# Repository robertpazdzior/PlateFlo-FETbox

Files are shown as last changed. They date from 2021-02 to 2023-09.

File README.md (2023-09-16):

# PlateFlo FETbox - Hardware Controller
FETbox hardware controller for the PlateFlo plate-scale perfusion tissue culture
system.

See [publication](https://doi.org/10.1016/j.ohx.2021.e00222) and [ReadTheDocs](https://plateflo.readthedocs.io) for a detailed description of the whole
system and documentation of its components. 

## Description
Hosted here are all of the necessary files to build a FETbox hardware
controller. Source files are also included should you need to make 
modifications for your application.
* [Enclosure](./Enclosure/STLs)
    * [STLs]() - for 3D printing
    * [CAD](./Enclosure/CAD) - STEP and F3D complete device models
* [PCB](./PCB)
    * [JLCPCB](https://jlcpcb.com/) CAM files (for PCB ordering)
    * [EAGLE](https://www.autodesk.com/products/eagle/overview) `.SCH` and `.BRD` [source files](./PCB/EAGLE)
* Arduino Nano FETbox [firmware](./Firmware_FETbox)

## License
This project is copyright of Robert Pazdzior (2020-2021)

It is provided under the terms of the [CERN Open Hardware License
(CERN-OHL-W)](https://cern-ohl.web.cern.ch/home). A copy of the license is
included [here](LICENSE).

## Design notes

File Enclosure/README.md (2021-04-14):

# Enclosure 3D Files
FETbox 3D-printing and CAD design resources. See [Build Guide](https://plateflo.readthedocs.io/en/latest/hardware/build_guide.html#d-printing-guidelines) for 3D-printing guidelines & assembly.

File | Description
---:  | :---
STLs\\*.stl | 3D print files. Oriented for FDM 3D-printing.
CAD\FETbox_complete.f3d | Complete Fusion360 model, including key board components.
CAD\FETbox_complete.step | As above, but compatible with open-source software.

## CAD Model Exploded Render
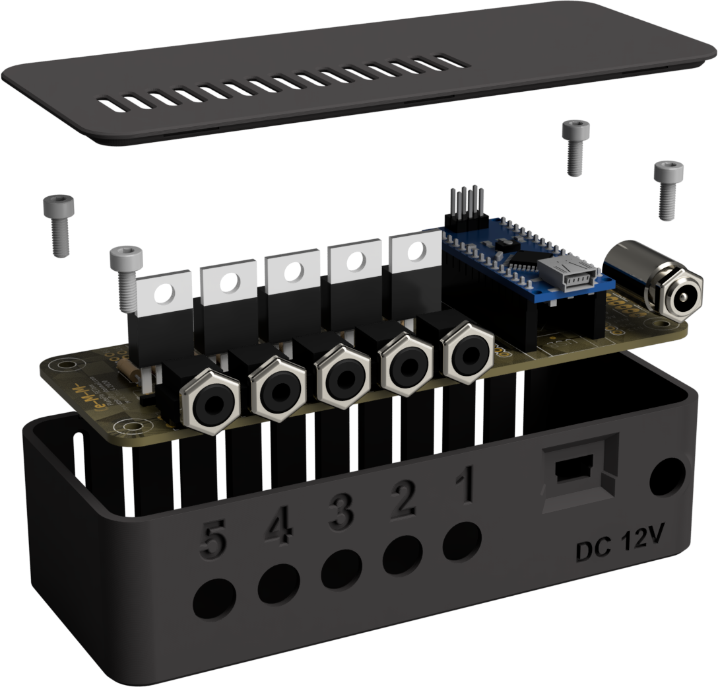
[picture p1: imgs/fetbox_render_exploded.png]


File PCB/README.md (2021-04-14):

# PCB
See [project documentation](https://plateflo.readthedocs.io/en/latest/hardware/build_guide.html#fetbox-hardware-controller) for manufacture and assembly guides.

## Files
File | Description
--- | ---
FETbox_rev0_Gerber_JLCPCB.zip | JLCPCB CAM (Gerber) files for production
EAGLE\FETbox_rev0_PCB.brd | EAGLE board
EAGLE\FETbox_rev0_PCB.sch | EAGLE schematic
EAGLE\\*.b#[0-9] | EAGLE routing support files
EAGLE\\*.pro | EAGLE auto-routing stats file
FETbox_rev0_schematic.pdf/dxf | Circuit diagram

## Overview
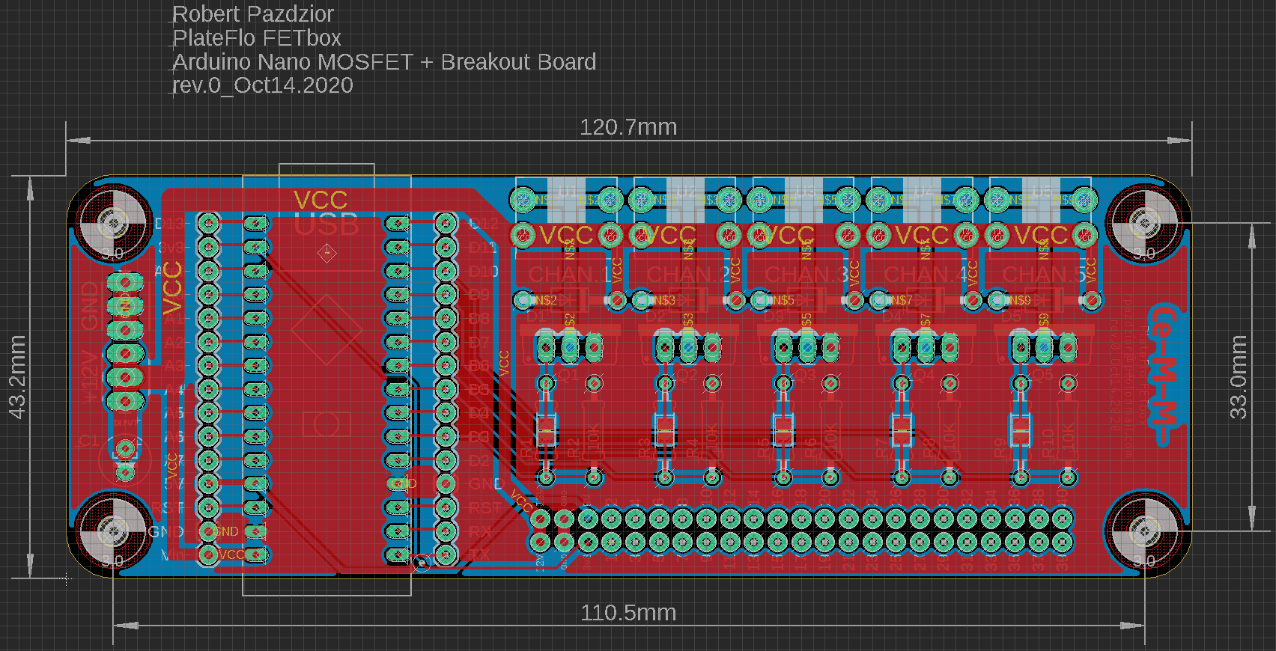
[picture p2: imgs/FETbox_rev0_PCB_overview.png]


## Top
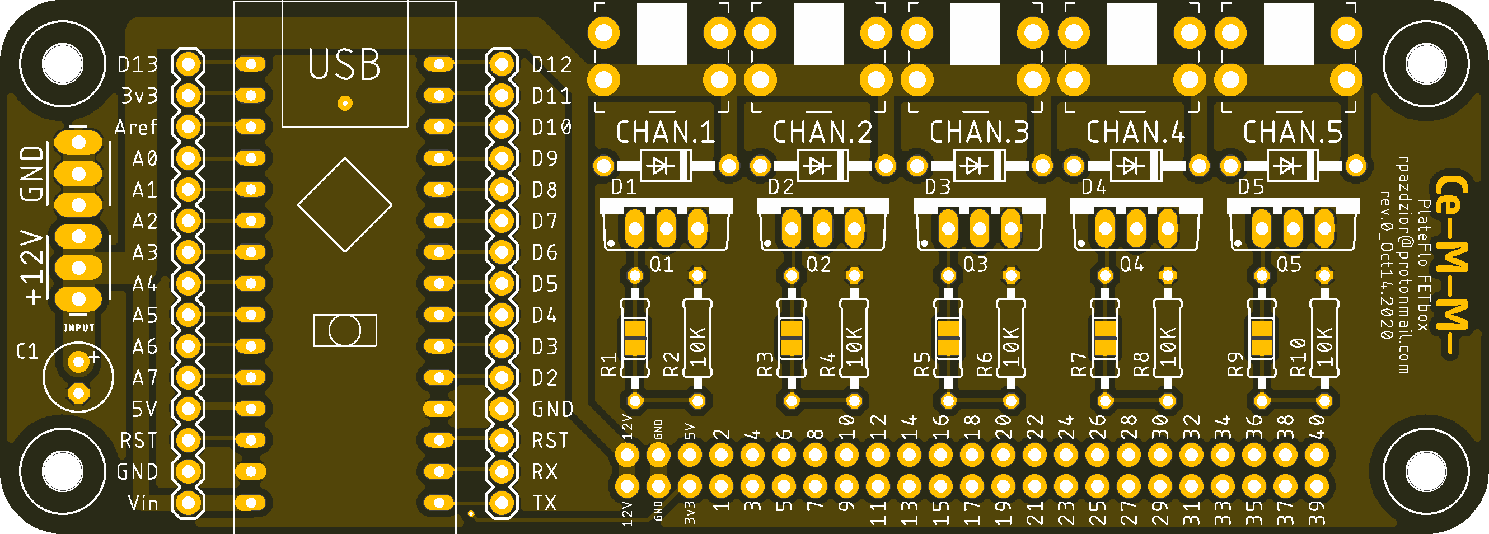
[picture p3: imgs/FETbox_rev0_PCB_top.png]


## Bottom
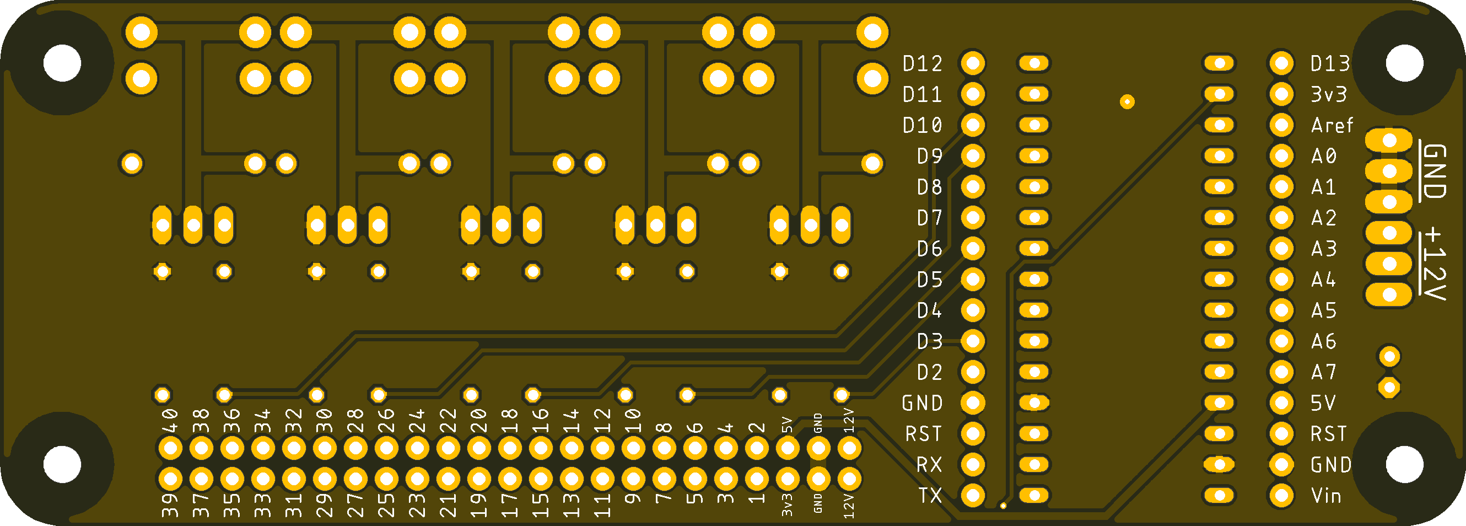
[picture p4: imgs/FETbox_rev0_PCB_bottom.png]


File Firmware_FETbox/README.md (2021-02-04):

# Firmware
FETbox firmware for the Arduino Nano v3. See documentation [here]().

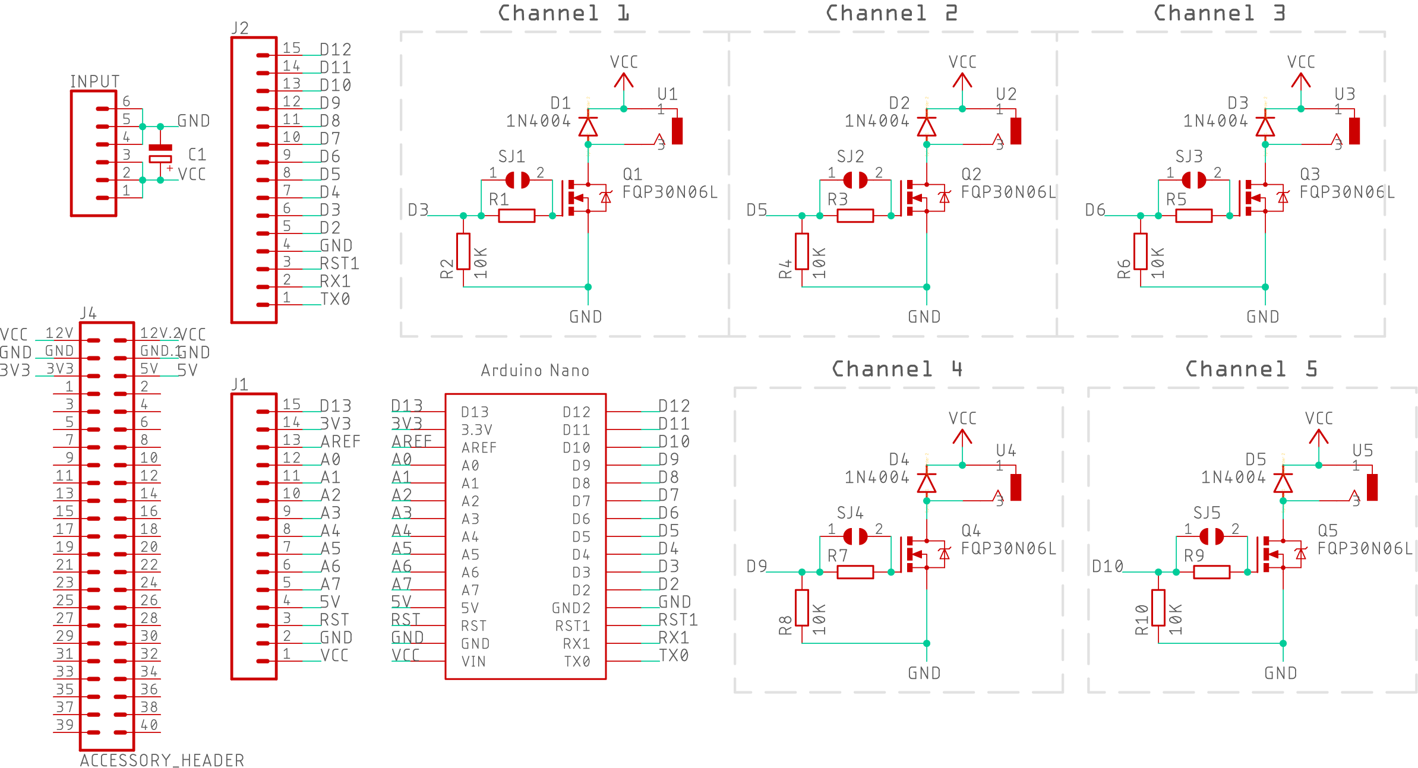
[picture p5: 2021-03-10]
imgs/FETbox_rev0_schematic.png

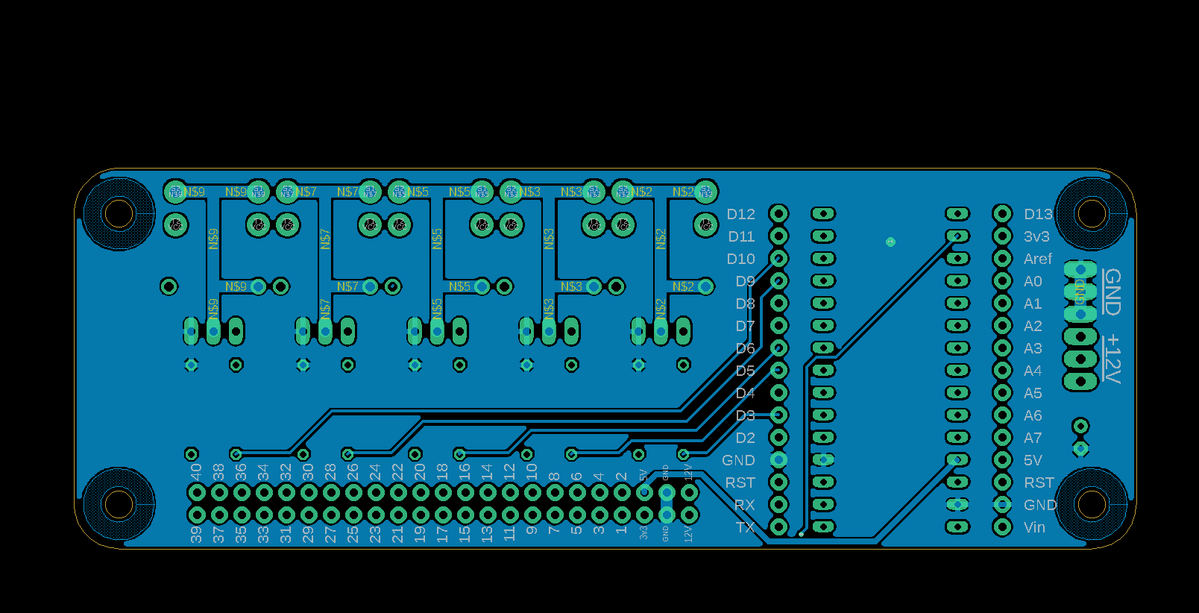
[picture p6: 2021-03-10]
imgs/PCB_bottom_copper.png

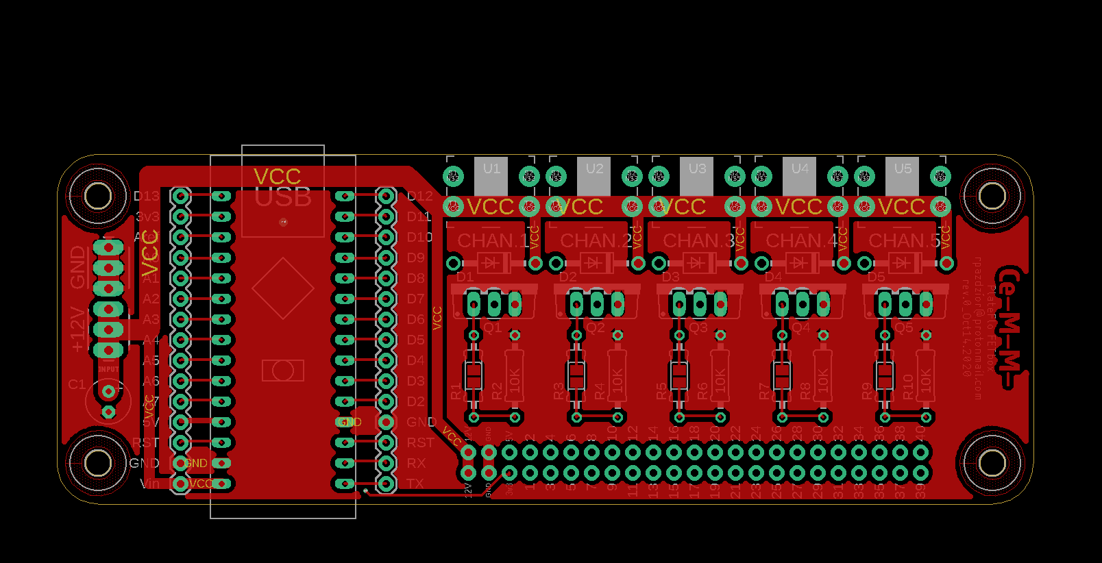
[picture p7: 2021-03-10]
imgs/PCB_top_copper.png

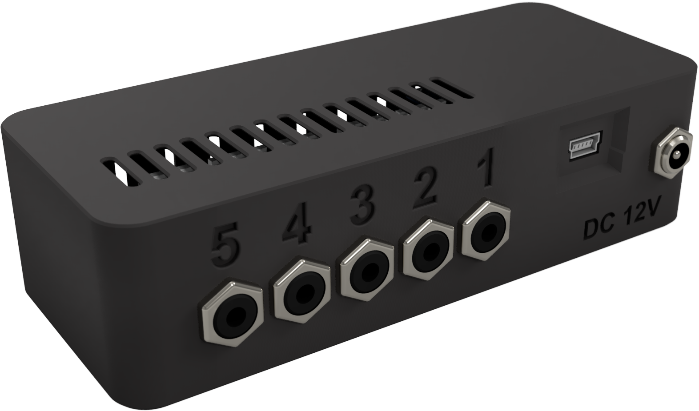
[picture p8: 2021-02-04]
imgs/fetbox_render.png

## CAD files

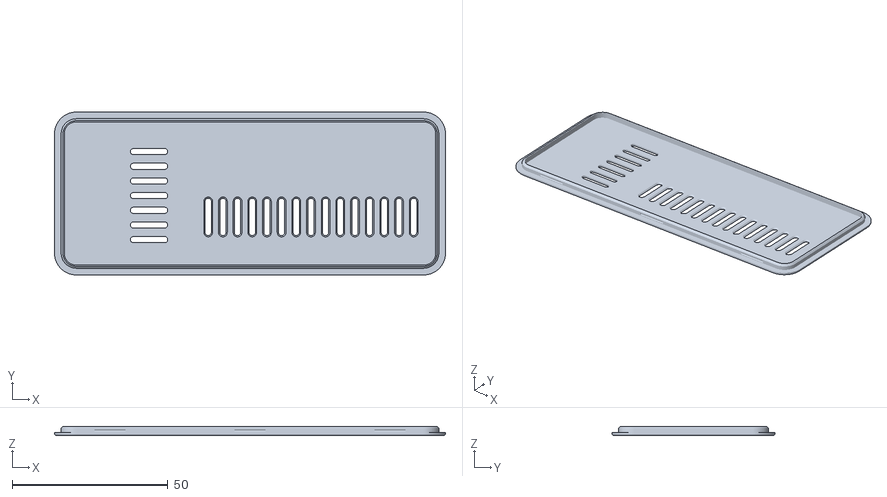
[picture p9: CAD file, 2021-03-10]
Enclosure/STLs/FETbox_enclosure_lid.stl
125.6 x 52.3 x 3.00

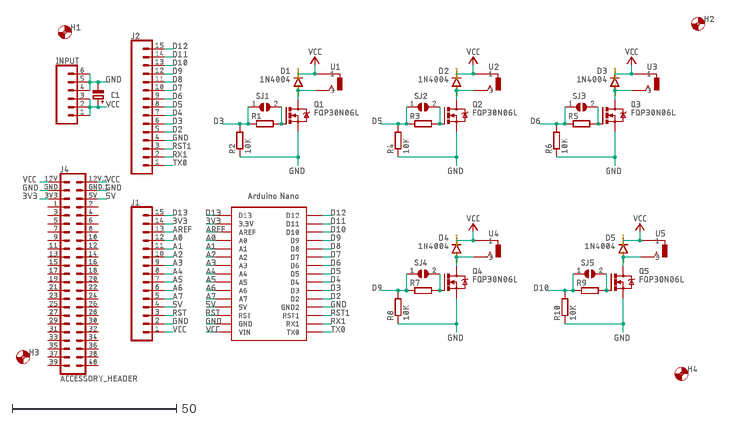
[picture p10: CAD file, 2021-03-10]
PCB/FETbox_rev0_PCB.dxf
212.5 x 111.5

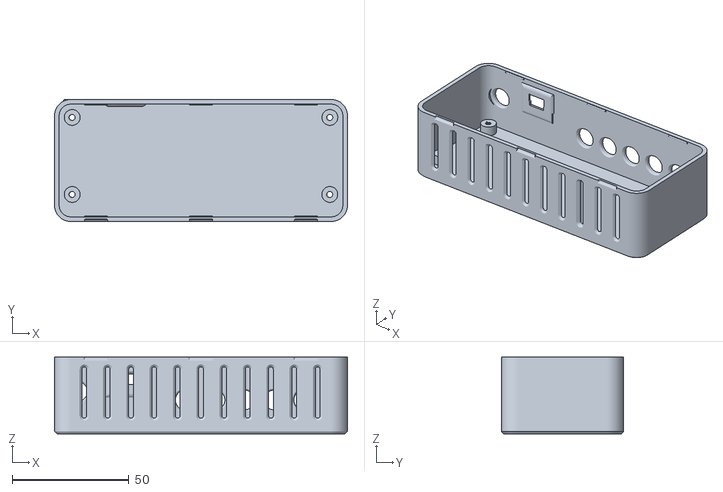
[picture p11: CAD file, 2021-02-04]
Enclosure/STLs/FETbox_enclosure_base.stl
125.6 x 52.3 x 32.9

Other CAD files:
Enclosure/CAD/FETbox_complete.f3d

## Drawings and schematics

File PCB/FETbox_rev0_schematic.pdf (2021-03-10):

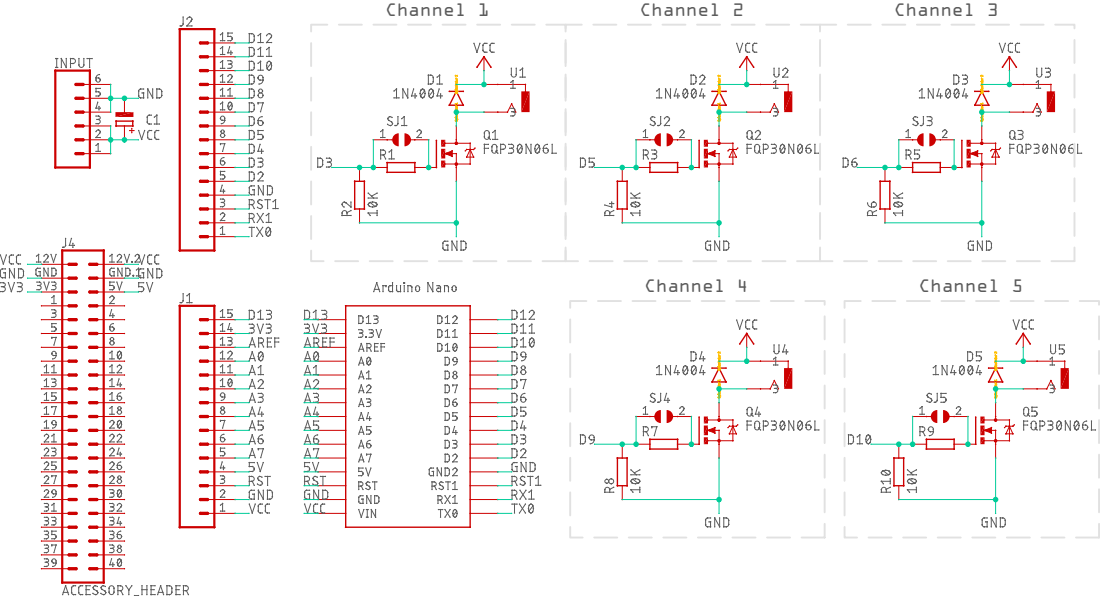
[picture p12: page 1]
Channel 1; Channel 2; Channel 3; Channel 4; Channel 5

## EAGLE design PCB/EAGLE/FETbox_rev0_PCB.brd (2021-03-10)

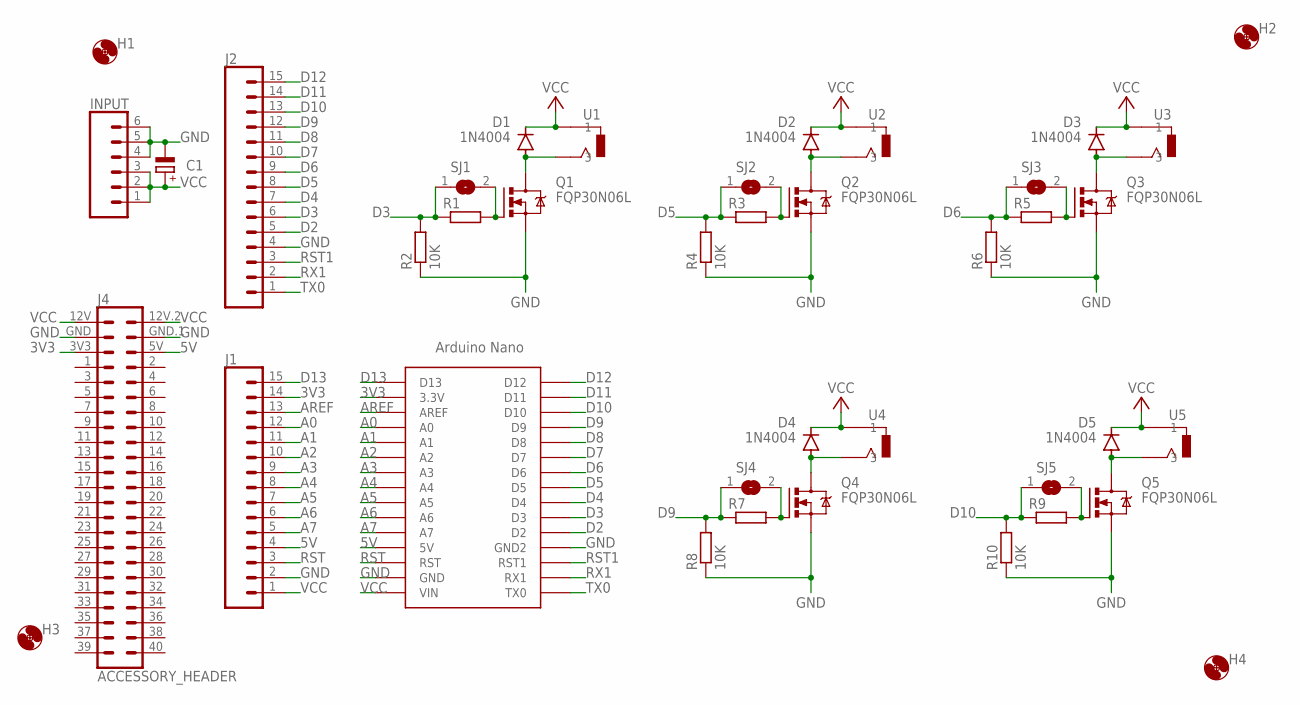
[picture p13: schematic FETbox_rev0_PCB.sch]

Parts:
C1: CPOL-EUE2.5-6; E2,5-6
D1, D2, D3, D4, D5: 1N4004; DO41-10
H1, H2, H3, H4: MOUNT-HOLE3.0; 3,0
INPUT: CONN_06LONGPADS; 1X06_LONGPADS
J1, J2: CONN_15; 1X15
J4: ACCESSORY_HEADER; 2X23
Q1, Q2, Q3, Q4, Q5: FQP30N06L; TO220
R1, R3, R5, R7, R9: 100; 0207/10
R2, R4, R6, R8, R10: 10K; 0207/10
SJ1, SJ2, SJ3, SJ4, SJ5: SJ
U1, U2, U3, U4, U5: CL13845G
U$2: NANO

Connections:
3V3: J1.14, J4.3V3, U$2.3.3V
5V: J1.4, J4.5V, U$2.5V
A0: J1.12, U$2.A0
A1: J1.11, U$2.A1
A2: J1.10, U$2.A2
A3: J1.9, U$2.A3
A4: J1.8, U$2.A4
A5: J1.7, U$2.A5
A6: J1.6, U$2.A6
A7: J1.5, U$2.A7
AREF: J1.13, U$2.AREF
D2: J2.5, U$2.D2
D3: J2.6, R1.1, R2.2, SJ1.1, U$2.D3
D4: J2.7, U$2.D4
D5: J2.8, R3.1, R4.2, SJ2.1, U$2.D5
D6: J2.9, R5.1, R6.2, SJ3.1, U$2.D6
D7: J2.10, U$2.D7
D8: J2.11, U$2.D8
D9: J2.12, R7.1, R8.2, SJ4.1, U$2.D9
D10: J2.13, R9.1, R10.2, SJ5.1, U$2.D10
D11: J2.14, U$2.D11
D12: J2.15, U$2.D12
D13: J1.15, U$2.D13
GND: C1.-, INPUT.4, INPUT.5, INPUT.6, J1.2, J2.4, J4.GND, J4.GND.1, Q1.S, Q2.S, Q3.S, Q4.S, Q5.S, R2.1, R4.1, R6.1, R8.1, R10.1, U$2.GND, U$2.GND1 (GND2)
unnamed: Q1.G, R1.2, SJ1.2
unnamed: D1.A, Q1.D, U1.S1 (3), U1.S2 (3)
unnamed: D2.A, Q2.D, U2.S1 (3), U2.S2 (3)
unnamed: Q2.G, R3.2, SJ2.2
unnamed: D3.A, Q3.D, U3.S1 (3), U3.S2 (3)
unnamed: Q3.G, R5.2, SJ3.2
unnamed: D4.A, Q4.D, U4.S1 (3), U4.S2 (3)
unnamed: Q4.G, R7.2, SJ4.2
unnamed: D5.A, Q5.D, U5.S1 (3), U5.S2 (3)
unnamed: Q5.G, R9.2, SJ5.2
RST: J1.3, U$2.RST
RST1: J2.3, U$2.RST1
RX1: J2.2, U$2.RX1
TX0: J2.1, U$2.TX0
VCC: C1.+, D1.C, D2.C, D3.C, D4.C, D5.C, INPUT.1, INPUT.2, INPUT.3, J1.1, J4.12V, J4.12V.2 (12V.1), U1.T1 (1), U1.T2 (1), U2.T1 (1), U2.T2 (1), U3.T1 (1), U3.T2 (1), U4.T1 (1), U4.T2 (1), U5.T1 (1), U5.T2 (1), U$2.RAW (VIN)

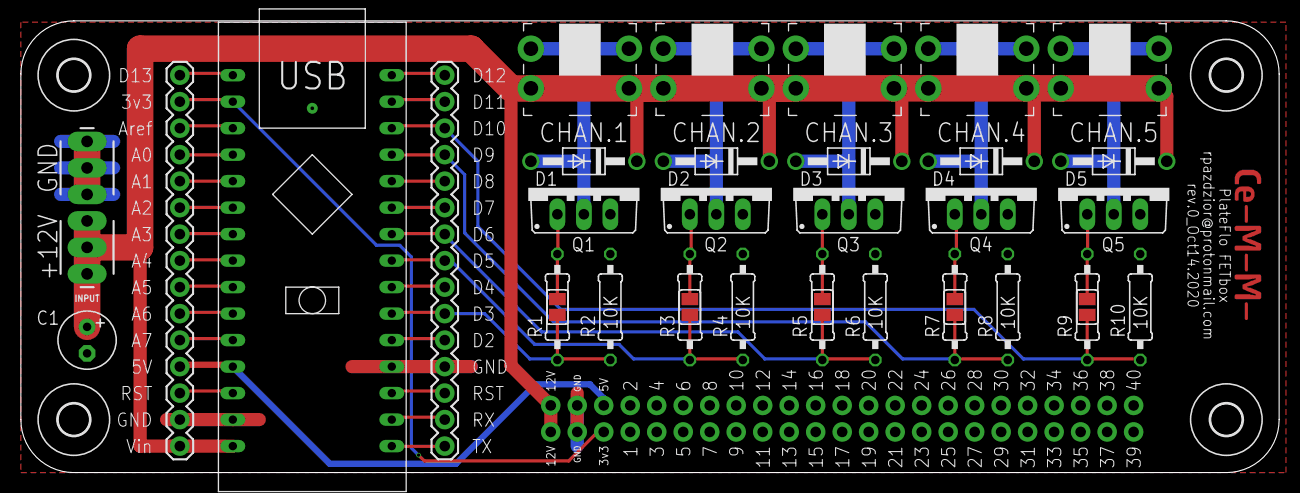
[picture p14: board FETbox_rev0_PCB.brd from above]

Board: 2 copper layers, 120.6 x 43.3 mm, 40 parts (0 on the bottom side), 39 nets.

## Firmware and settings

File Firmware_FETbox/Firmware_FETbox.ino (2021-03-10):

/* 
  Firmware for PlateFlo FETbox hardware controller. 
  Target PCB rev.0, Arduino Nano V3
  
  Copyright Robert Pazdzior (2020-2021)
  github.com/robertpazdzior/PlateFlo-FETbox
  rpazdzior@protonmail.com
  
  Licensed under CERN Open Hardware License (CERN-OHL-W)
*/

/*======CONFIG=====*/
#define BAUD 115200 // USB serial baud rate
#define ID 0		    // Controller ID [0-9], change when using multiple units
/*=================*/

/* ============== !!!!!!!!!!!!!!!!!! ===================
MULTIPLY ANY DELAY OR MICROS READING BY THE FACTOR BELOW
Otherwise comment out the timer freq change in setup(),
reducing the PWM output of D5, D6 to the audible range.
======================================================*/
#define TMR_FACTOR 64

/* Macros for serial command parsing */
#define CMD_START     '@'   // start of command character
#define CMD_END       '\n'  // end of command character

#define CMD_ID        '#'   // query device ID
#define CMD_HEARTBEAT '?'   // ping device heartbeat
#define CMD_ENABLE    'H'   // enable channel output
#define CMD_DISABLE   'I'   // disable channel output
#define CMD_HIT_HOLD  'V'   // 'hit and hold' channel output
#define CMD_PWM       'S'   // set channel output PWM duty (0-255)
#define CMD_DIG_READ  'D'   // read digital pin
#define CMD_ANA_READ  'A'   // read analog pin
#define CMD_DIG_WRITE 'E'   // write value to digital pin
#define CMD_ANA_WRITE 'B'   // write 10-bit value to analog pin

/*
Command structure:
    @[CMD]<[PARAM_1]><[PARAM_2]>...<[PARAM_n]>\n
    |  |    |             |             |      |
    |  |    |             |             |      Line feed (LF)
    |  |    |             |             
    |  |    |             Additional parameters, variable length
    |  |    Additional parameter, eg. channel #
    |  Command, single ASCII character
    Command start
*/

#define PIN_CHAN1 3
#define PIN_CHAN2 5
#define PIN_CHAN3 6
#define PIN_CHAN4 9
#define PIN_CHAN5 10

int chan_pin[5] = {PIN_CHAN1, PIN_CHAN2, PIN_CHAN3, PIN_CHAN4, PIN_CHAN5};
char inCmd[20];

void hit_n_hold(int _pin, int _duty = 127, int _delay = 100) {
  /* Reduces heat in solenoid valves, might require tuning of *_duty* */
  digitalWrite(_pin, HIGH); // Hit
  delay(_delay * TMR_FACTOR);
  analogWrite(_pin, _duty); // Hold
}

void ack() {
  /* Respond command success */
  Serial.write("*\n");
}

void ack_err() {
  /* Respond command error */
  Serial.write("#\n");
}

void serial_listen(char* cmdArray) {
    unsigned int lenCmd = 20;
    char inCmd[lenCmd];
    bool cmdStarted = false, cmdFinished = false;
    unsigned int idx;

    while(Serial.available() > 0 | cmdStarted) {
      if(Serial.available() > 0) {
        char inChar = Serial.read();
        if( (inChar == CMD_END) && cmdStarted) {
            cmdFinished = true;
        }

        else if (inChar == CMD_START) {
            cmdStarted = true;
            cmdFinished = false;
            idx = 0;
        }

        else if (cmdStarted && !cmdFinished && ( (idx+1) <= lenCmd) ) {
            inCmd[idx] = inChar;
            idx++;
            inCmd[idx] = '\0';
        }

        if (cmdStarted && cmdFinished) {
            idx = 0;
            cmdStarted = false;
            cmdFinished = false;

            /* Write to cmd array when finished */
            memcpy(cmdArray, inCmd, lenCmd);

            for(uint16_t i = 0; i < sizeof(inCmd); i++) {
               inCmd[i] = '\0';
            }
        }
      }
    }
}

void cmd_interpret(char* cmd) {
    /* Module ID query */
    if(cmd[0] == CMD_ID) {
      Serial.print("fetbox");
      Serial.print(ID);
      Serial.write("\n");
    }

    /* Heartbeat */
    else if(cmd[0] == CMD_HEARTBEAT) {
        ack();
    }

    /* Enable channel output */
    else if(cmd[0] == CMD_ENABLE) {
      int _chan = (cmd[1]-'0');
      if( (_chan > 0) & (_chan < 6) ) {
        digitalWrite(chan_pin[_chan-1], HIGH);
        ack();
      }
      else {
        ack_err();
      }
    }

    /* Enable channel output with hit/hold power reduction */
    else if(cmd[0] == CMD_HIT_HOLD) {
      int _chan = (cmd[1]-'0');
      bool _validParams = true;
      
      char _tempPWM[4];

      for(int i=2; i < 5; i++) {
        if(cmd[i] == '\0') _validParams = false;
        _tempPWM[i-2] = cmd[i];
      }
      _tempPWM[4] = '\0';
      int _pwm = atoi(_tempPWM);
      if( (_pwm < 0) | (_pwm > 255) ) _validParams = false;

      if( (_chan > 0) & (_chan < 6) & _validParams) {
        hit_n_hold(chan_pin[_chan-1], _pwm);
        ack();
      }
      else {
        ack_err();
      }
    }

    /* Enable channel output at given PWM duty cycle */
    else if(cmd[0] == CMD_PWM) {
      bool _validParams = true;
      int _chan = (cmd[1]-'0');
      char _tempPWM[4];

      for(int i=2; i < 5; i++) {
        if(cmd[i] == '\0') _validParams = false;
        _tempPWM[i-2] = cmd[i];
      }
      _tempPWM[4] = '\0';

      int _pwm = atoi(_tempPWM);
      if( (_pwm < 0) | (_pwm > 255) ) _validParams = false;

      if( (_chan > 0) & (_chan < 6) & _validParams) {
        analogWrite(chan_pin[_chan-1], _pwm);
        ack();
      }
      else {
        ack_err();
      }
    }

    /* Disable channel output */
    else if(cmd[0] == CMD_DISABLE) {
      int _chan = (cmd[1]-'0');
      if( (_chan > 0) & (_chan < 6) ) {
        digitalWrite(chan_pin[_chan-1], LOW);
        ack();
      }
      else {
        ack_err();
      }
    }

    /* Read digital pin */
    else if (cmd[0] == CMD_DIG_READ) {
      char _tempPin[3];

      // Parse command for pin, convert to integer
      for(int i=1; i < 3; i++) {
        _tempPin[i-1] = cmd[i];
      }
      _tempPin[3] = '\0';
      int _pin = atoi(_tempPin);

      // Validate pin number: 0-13 => D0-D13; 14-19 => A0-A5 (A6/A7 analog-only)
      if( (_pin >= 0) & (_pin < 20) ) {
        int reading = digitalRead(_pin);
        Serial.print(reading);
        Serial.print('\n');
      }
      else {
        ack_err();
      }
    }

    /* Read analog pin */
    else if (cmd[0] == CMD_ANA_READ) {
      char _tempPin[3];

      // Parse command for pin, convert to integer
      for(int i=1; i < 3; i++) {
        _tempPin[i-1] = cmd[i];
      }
      _tempPin[3] = '\0';
      int _pin = atoi(_tempPin);

      // Validate pin number: 14-21 => A0-A7
      if( (_pin > 13) & (_pin < 22) ) {
        int reading = analogRead(_pin);
        Serial.print(reading);
        Serial.print('\n');
      }
      else {
        ack_err();
      }
    }

    /* Write digital pin */
    else if (cmd[0] == CMD_DIG_WRITE) {
      char _tempPin[3];
      char _tempVal[2];

      // Parse command for pin, convert to integer
      for(int i=1; i < 3; i++) {
        _tempPin[i-1] = cmd[i];
      }
      _tempPin[3] = '\0';
      int _pin = atoi(_tempPin);

      // Parse command for output value, convert to integer
      _tempVal[0] = cmd[3];
      _tempVal[1] = '\0';
      int _val = atoi(_tempVal);

      // Validate pin number: 0-13 => D0-D13; 14-19 => A0-A5 (A6/A7 analog-only)
      // and value (0-1)
      if( ( (_pin >= 0) & (_pin < 22) ) & ( (_val == 1) | (_val == 0) )) {
        digitalWrite(_pin, _val);
        ack();
      }
      else {
        ack_err();
      }
    }


    /* Write PWM pin */
    else if (cmd[0] == CMD_ANA_WRITE) {
      char _tempPin[3];
      char _tempVal[4];

      // Parse command for pin, convert to integer
      for(int i=1; i < 3; i++) {
        _tempPin[i-1] = cmd[i];
      }
      _tempPin[3] = '\0';
      int _pin = atoi(_tempPin);

      // Parse command for PWM value, convert to integer
      for(int i=3; i < 6; i++) {
        _tempVal[i-3] = cmd[i];
      }
      _tempVal[4] = '\0';
      int _pwm = atoi(_tempVal);

      // Validate pin number: Nano PWM pins = 3,5,6,9,10,11. PWM value 0-255.
      if( ( (_pin == 3) | (_pin == 5) | (_pin == 6) | ( (_pin >= 9) & (_pin < 12) ) ) & ( (_pwm >= 0) & (_pwm < 256) ) ) {
        analogWrite(_pin, _pwm);
        ack();
      }
      else {
        ack_err();
      }
    }

    /* Malformed/invalid command */
    else if(cmd[0] != '\0') {
      ack_err();
    }

    /* Reset cmd array */
    for(uint16_t i = 0; i < sizeof(cmd); i++) {
        cmd[i] = '\0';
    }
}

void setup() {
  Serial.begin(BAUD);
  pinMode(PIN_CHAN1, OUTPUT);
  pinMode(PIN_CHAN2, OUTPUT);
  pinMode(PIN_CHAN3, OUTPUT);
  pinMode(PIN_CHAN4, OUTPUT);
  pinMode(PIN_CHAN5, OUTPUT);

  // Adjust PWM frequencies above audible range.
  // More info: https://arduinoinfo.mywikis.net/wiki/Arduino-PWM-Frequency
  TCCR2B = TCCR2B & B11111000 | B00000001; // Pin 3 PWM freq. to 31.37kHz
  TCCR0B = TCCR0B & B11111000 | B00000001; // Pin 5&6 PWM freq. to 62.5kHz. AFFECTS DELAY AND MICROS !!!
  TCCR1B = TCCR1B & B11111000 | B00000001; // Pin 9&10 PWM freq. to 31.37kHz
}

void loop() {
  serial_listen(inCmd);
  cmd_interpret(inCmd);
}

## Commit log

2021-02-04 files, images, markdowns
    [FETbox_complete.f3d, FETbox_enclosure_base.stl, FETbox_enclosure_lid.stl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]
2021-02-04 STL link fixed
2021-02-04 enclosure img link
2021-03-10 sketch improved, fetbox lid, schematics
    [FETbox_complete.f3d, FETbox_enclosure_lid.stl, FETbox_rev0_PCB.brd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]

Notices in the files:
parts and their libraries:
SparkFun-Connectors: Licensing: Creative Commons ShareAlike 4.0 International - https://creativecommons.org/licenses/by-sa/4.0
